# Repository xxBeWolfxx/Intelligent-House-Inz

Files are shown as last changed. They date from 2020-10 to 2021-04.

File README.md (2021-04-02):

# Projekt, praca dyplomowa pod tytułem "Układ sterowania inteligentnego budynku mieszkalnego "
Projekt został zrealizowany w ramach pracy dyplomowej na uczelni wyższej, Politechniki Poznańskiej. Miała ona na celu opracowania systemu do zarządzania domostwem.

## Założenia aplikacji: 
### Funkcje aplikacji:
   - Opracowanie układu kontroli i sterowania budynkiem mieszkalnym
   - Opracowanie mobilnego interfejsu uzytkownika
   - Opracowanie układu komunikacji głosowej

Aplikacja składa się z 4 elementów: Komputera (asystent Google'a, serwer, baza danych), Aplikacja (interfejs użytkownika), ESP Sensors (pobieranie danych z czujników), ESP Outputs (zarządzanie załączaniem urządzeń).
## Komputer.
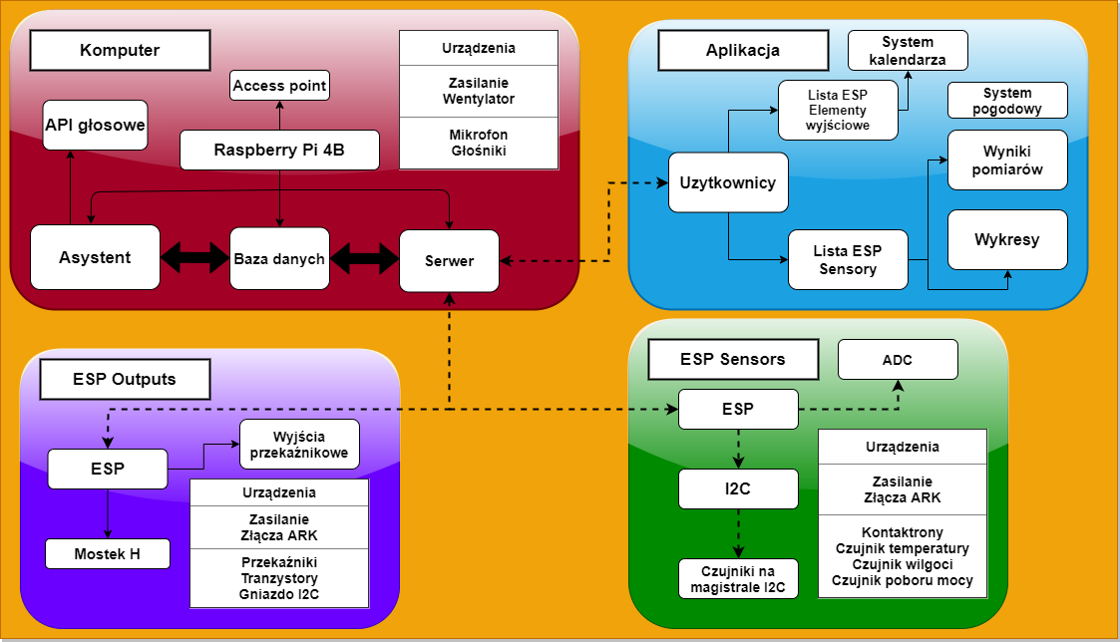
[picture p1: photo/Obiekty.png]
Diagram

Jako komputer został zaimplementowany komputer Raspberry Pi 4B, który posiada w sobie instancje:
#### Serwer.
Został zrealizowany za pomocą frameworku Django oraz Django REST framework. Została stworzona strona administracyjna do szybkiego modelowania informacji w bazie.
Link: https://github.com/xxBeWolfxx/Django-server

### Baza danych.
Ze względu na wykorzystanie systemu operacyjnego Debian została zaimplementowana baza SQL w dystrybucji MariaDB. Baza posiada tablice: Użytkownik, ESP Sensor, ESP Output. Tablice ESP Sensor oraz ESP Output są w relacji Many-to-Many z tablicą Użytkownik.

#### Asystent.
Asystent został zaimplementowany jako gotowe rozwiązanie GassistPI[www] https://gassistpi-documentation.readthedocs.io. Wymieniony SDK korzysta z rozwiązań Asystenta Google'a. Zostały również dodane skrypty do sterowania płytką ESP Outputs. 

### Płytki PCB.
Zaprojektowano dwa typy płytek w programie Eagle, które są uniwersalne i mają możliwość podłączenia różnych urządzeń. Napięcie zasilające może osiągać wartość od 10 do 20 Voltów DC. 
#### ESP Sensors
Zawiera:
- 4 porty ADC (2x port z 5V, 2x port 3V3),
- 5 portów kontaktronów, badanie statusu pinów czy zostały zwarte czy rozwarte.
- 4 porty magistrali I2C (2x port z 5V, 2x port 3V3).

#### ESP Outputs
- 5 portów przekaźnikowych zasilonych napięciem zasilania. 
- 2 porty do sterowania silnikiem DC.

### Aplikacja
Składa się ona z dwóch aktywności: uwierzytelnienie użytkownika oraz zarządzanie urządzeniami i sensorami w sieci. Zaimplementowano wykresy wartości czujników. Aplikacja współpracuje ściśle z serwerem i komunikuje się z nim po protokole HTTP REST Api.

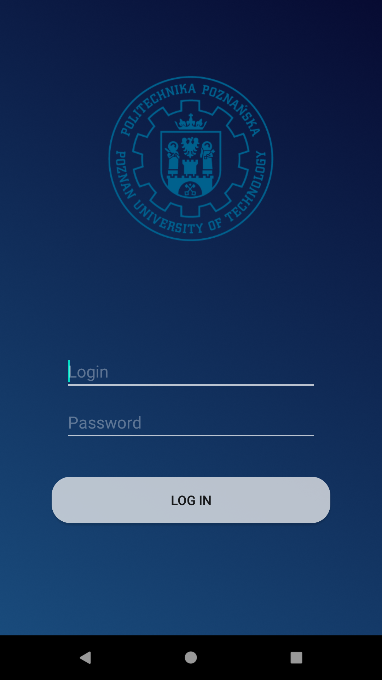
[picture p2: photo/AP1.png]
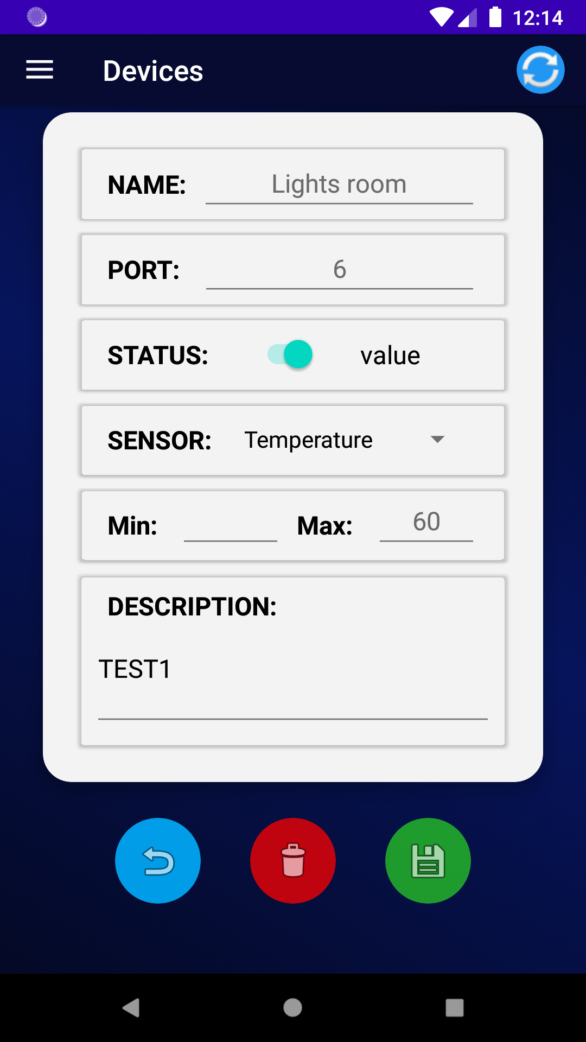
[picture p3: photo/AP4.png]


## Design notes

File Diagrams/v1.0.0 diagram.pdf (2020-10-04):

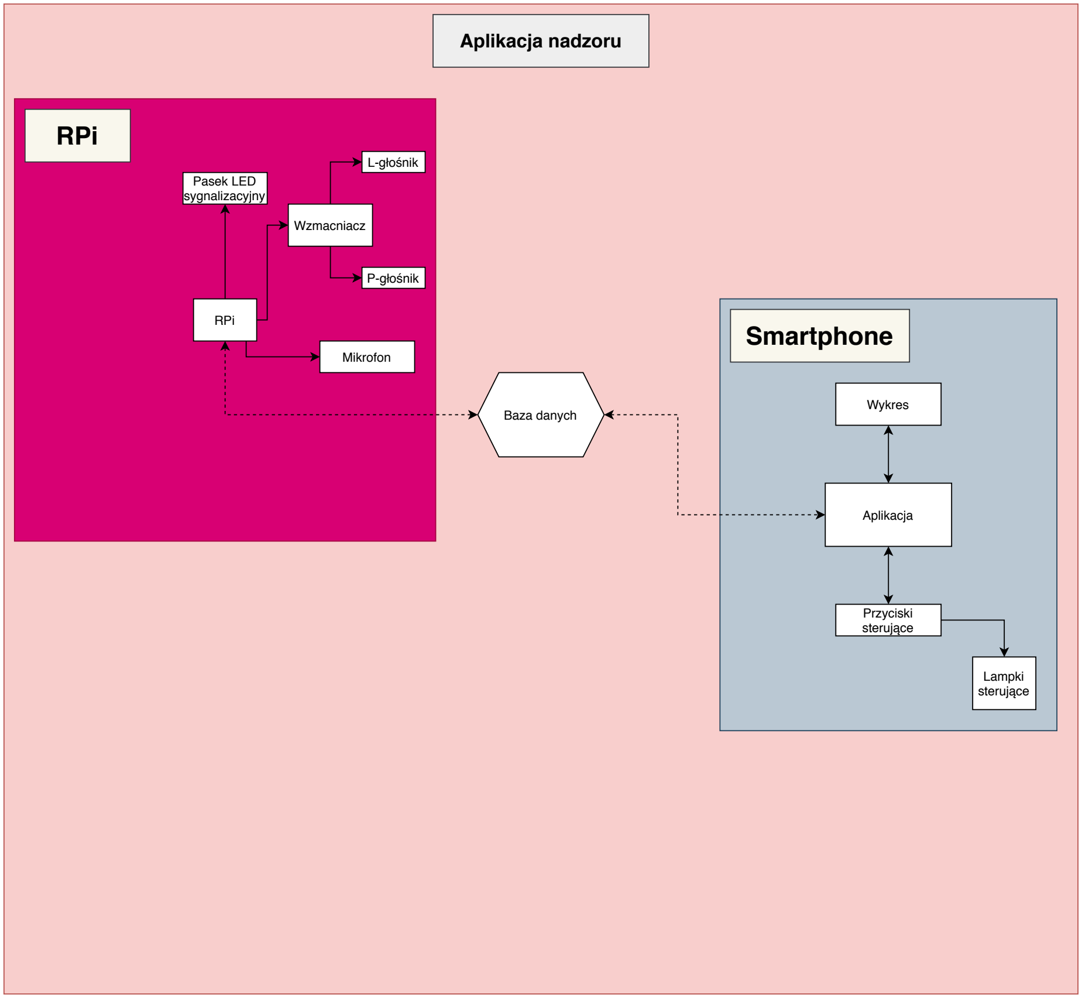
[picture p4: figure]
Aplikacja nadzoru; RPi; Smartphone; Wzmacniacz; L-głośnik; P-głośnik; Mikrofon; Baza danych; Aplikacja; Pasek LED sygnalizacyjny; Wykres; Przyciski sterujące; Lampki sterujące

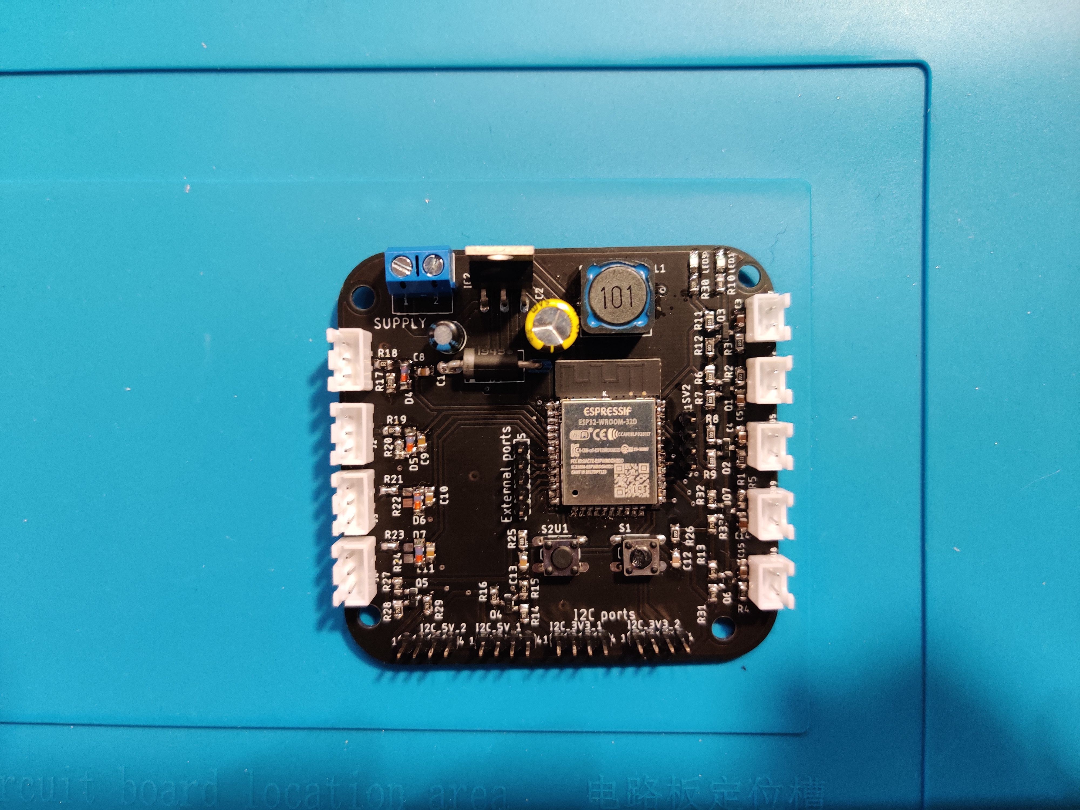
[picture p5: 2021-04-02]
photo/sensor.jpg

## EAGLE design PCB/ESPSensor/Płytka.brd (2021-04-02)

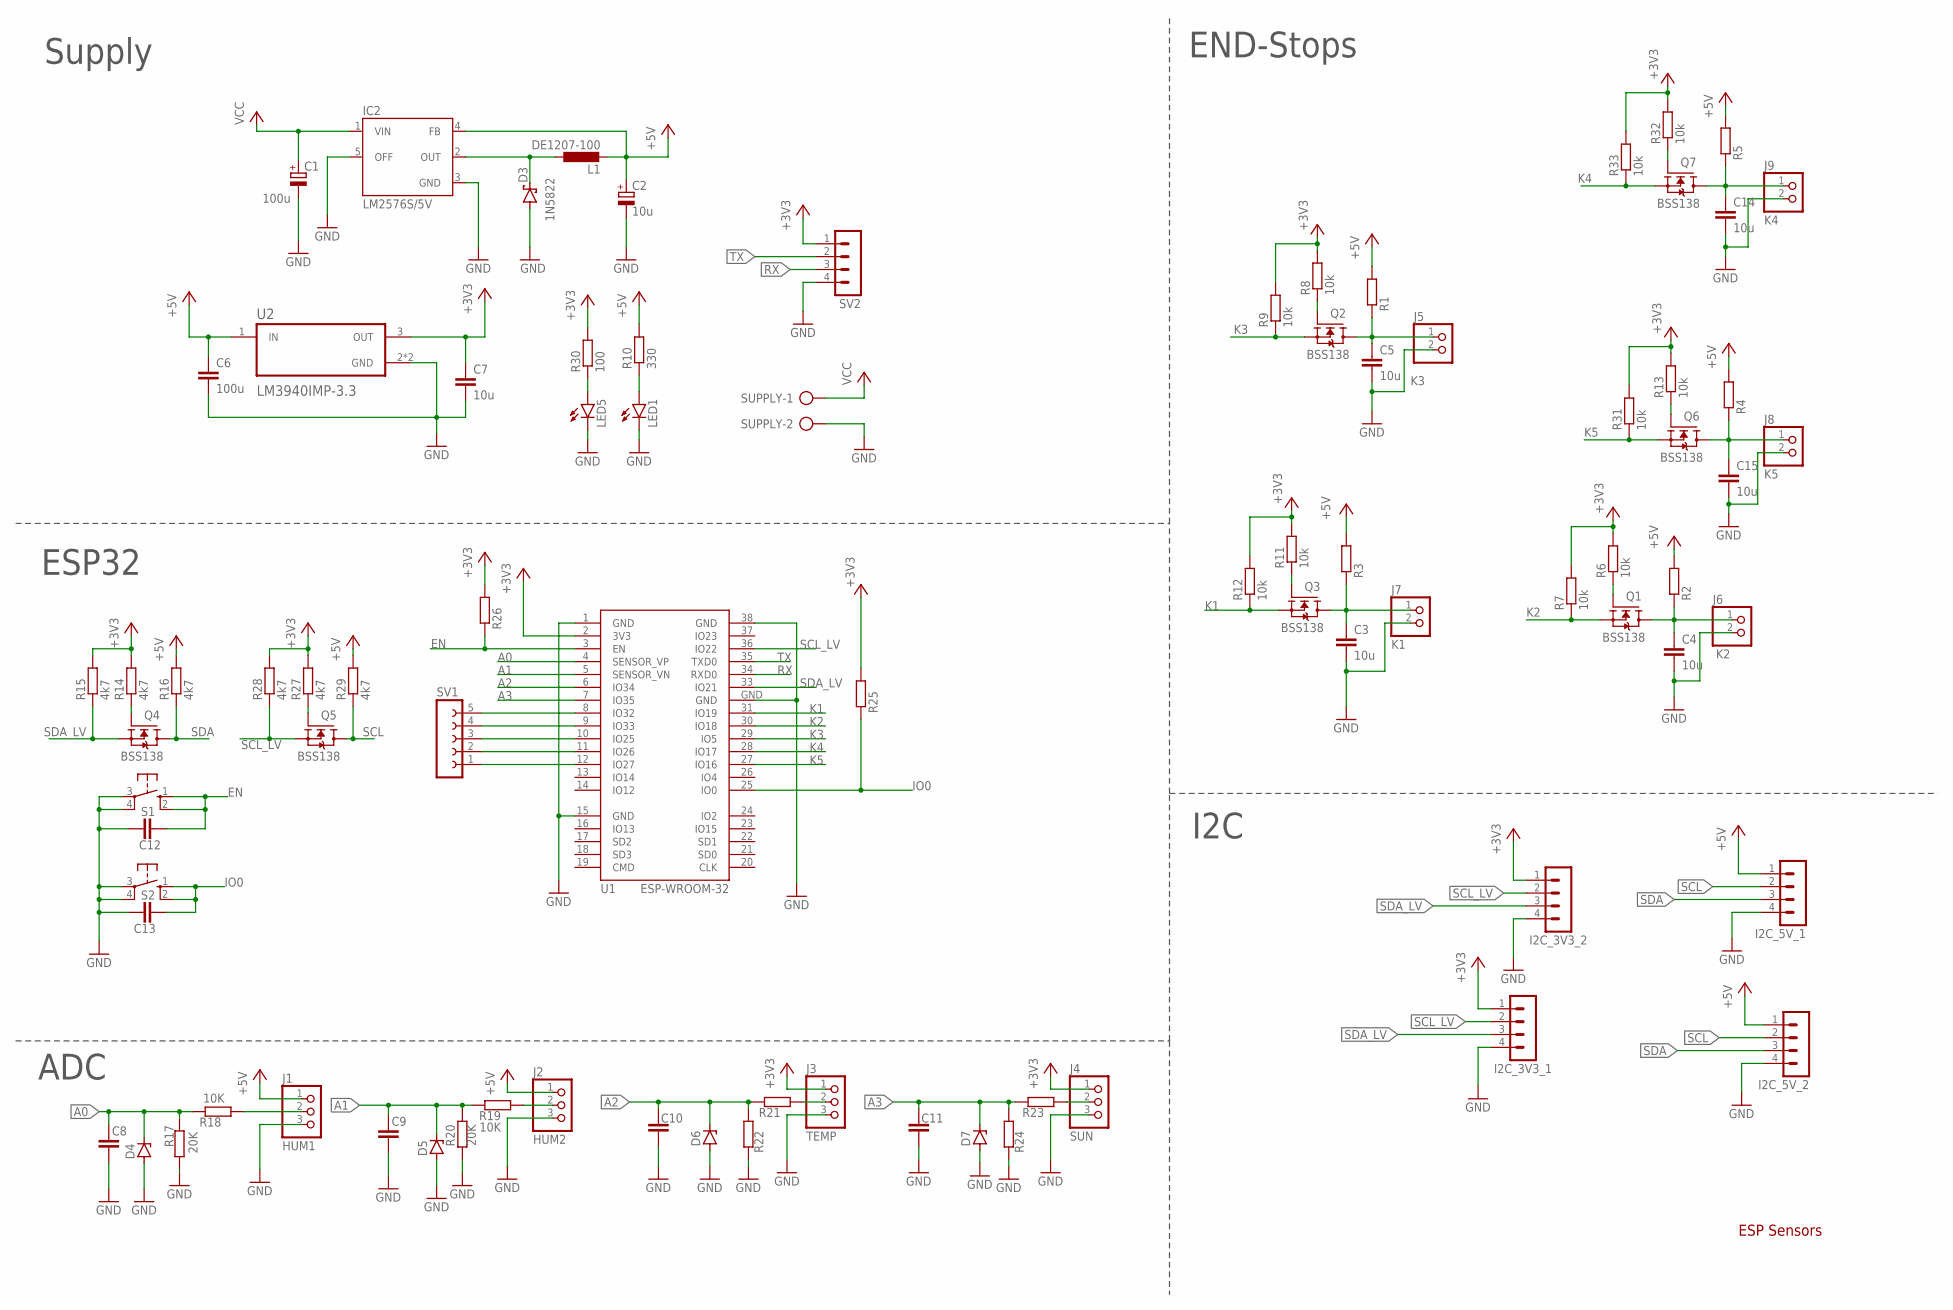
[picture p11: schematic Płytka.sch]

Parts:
C1: 100u; E2,5-6
C2: 10u; E3,5-8
C3, C4, C5, C7, C14, C15: 10u; C0805K
C6: 100u; C0805K
C8, C9, C10, C11, C12, C13: C-EUC0805K; C0805K
D3: 1N5822; C4111-15
D4, D5, D6, D7: ZENER-DIODESOD80C; SOD80C
I2C_3V3_1, I2C_3V3_2, I2C_5V_1, I2C_5V_2: MA04-1
IC2: LM2576S/5V; TO220-5
J1: HUM1; W_TYPE_2MM_3_N
J2: HUM2; W_TYPE_2MM_3_N
J3: TEMP; W_TYPE_2MM_3_N
J4: SUN; W_TYPE_2MM_3_N
J5: K3; W_TYPE_2MM_2_N
J6: K2; W_TYPE_2MM_2_N
J7: K1; W_TYPE_2MM_2_N
J8: K5; W_TYPE_2MM_2_N
J9: K4; W_TYPE_2MM_2_N
L1: DE1207-100; DE1207
LED1, LED5: LEDSML0805; SML0805
Q1, Q2, Q3, Q4, Q5, Q6, Q7: BSS138; SOT23
R1, R2, R3, R4, R5, R21, R22, R23, R24, R25, R26: R-EU_R0805; R0805
R6, R7, R8, R9, R11, R12, R13, R31, R32, R33: 10k; R0805
R10: 330; R0805
R14, R15, R16, R27, R28, R29: 4k7; R0805
R17, R20: 20K; R0805
R18, R19: 10K; R0805
R30: 100; R0805
S1, S2: 10-XX; B3F-10XX
SUPPLY: AK500/2-H
SV1: FE05-1
SV2: MA04-1
U1: ESP-WROOM-32
U2: LM3940IMP-3.3; SOT230P700X180-4N

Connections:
+3V3: C7.1, I2C_3V3_1.1, I2C_3V3_2.1, J3.1, J4.1, R6.2, R7.2, R8.2, R9.2, R11.2, R12.2, R13.2, R14.2, R15.2, R25.2, R26.2, R27.2, R28.2, R30.2, R31.2, R32.2, R33.2, SV2.1, U1.2 (3V3), U2.3 (OUT)
+5V: C2.+, C6.1, I2C_5V_1.1, I2C_5V_2.1, IC2.4 (FB), J1.1, J2.1, L1.2, R1.2, R2.2, R3.2, R4.2, R5.2, R10.2, R16.2, R29.2, U2.1 (IN)
A0: C8.1, D4.C, R17.2, R18.2, U1.4 (SENSOR_VP)
A1: C9.1, D5.C, R19.2, R20.1, U1.5 (SENSOR_VN)
A2: C10.1, D6.C, R21.2, R22.1, U1.6 (IO34)
A3: C11.1, D7.C, R23.2, R24.1, U1.7 (IO35)
EN: C12.2, R26.1, S1.1 (S), S1.2 (S1), U1.3 (EN)
GND: C1.-, C2.-, C3.2, C4.2, C5.2, C6.2, C7.2, C8.2, C9.2, C10.2, C11.2, C12.1, C13.1, C14.2, C15.2, D3.A, D4.A, D5.A, D6.A, D7.A, I2C_3V3_1.4, I2C_3V3_2.4, I2C_5V_1.4, I2C_5V_2.4, IC2.3 (GND), IC2.5 (OFF), J1.3, J2.3, J3.3, J4.3, J5.2, J6.2, J7.2, J8.2, J9.2, LED1.C, LED5.C, R17.1, R20.2, R22.2, R24.2, S1.3, S1.4 (P1), S2.3, S2.4 (P1), SUPPLY.2, SV2.4, U1.1 (GND), U1.15 (GND), U1.38 (GND), U1.GND, U2.2 (GND), U2.4 (GND)
IO0: C13.2, R25.1, S2.1 (S), S2.2 (S1), U1.25 (IO0)
K1: Q3.2 (S), R12.1, U1.31 (IO19)
K2: Q1.2 (S), R7.1, U1.30 (IO18)
K3: Q2.2 (S), R9.1, U1.29 (IO5)
K4: Q7.2 (S), R33.1, U1.28 (IO17)
K5: Q6.2 (S), R31.1, U1.27 (IO16)
unnamed: C5.1, J5.1, Q2.3 (D), R1.1
unnamed: C4.1, J6.1, Q1.3 (D), R2.1
unnamed: LED1.A, R10.1
unnamed: Q4.1 (G), R14.1
unnamed: C3.1, J7.1, Q3.3 (D), R3.1
unnamed: C14.1, J9.1, Q7.3 (D), R5.1
unnamed: C15.1, J8.1, Q6.3 (D), R4.1
unnamed: Q5.1 (G), R27.1
unnamed: J1.2, R18.1
unnamed: SV1.5, U1.8 (IO32)
unnamed: Q1.1 (G), R6.1
unnamed: SV1.4, U1.9 (IO33)
unnamed: Q2.1 (G), R8.1
unnamed: SV1.3, U1.10 (IO25)
unnamed: J4.2, R23.1
unnamed: Q3.1 (G), R11.1
unnamed: SV1.2, U1.11 (IO26)
unnamed: J2.2, R19.1
unnamed: D3.C, IC2.2 (OUT), L1.1
unnamed: Q6.1 (G), R13.1
unnamed: J3.2, R21.1
unnamed: SV1.1, U1.12 (IO27)
unnamed: LED5.A, R30.1
unnamed: Q7.1 (G), R32.1
RX: SV2.3, U1.34 (RXD0)
SCL: I2C_5V_1.2, I2C_5V_2.2, Q5.3 (D), R29.1
SCL_LV: I2C_3V3_1.2, I2C_3V3_2.2, Q5.2 (S), R28.1, U1.36 (IO22)
SDA: I2C_5V_1.3, I2C_5V_2.3, Q4.3 (D), R16.1
SDA_LV: I2C_3V3_1.3, I2C_3V3_2.3, Q4.2 (S), R15.1, U1.33 (IO21)
TX: SV2.2, U1.35 (TXD0)
VCC: C1.+, IC2.1 (VIN), SUPPLY.1

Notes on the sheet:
Supply
ESP32
ADC
I2C
END-Stops
ESP Sensors

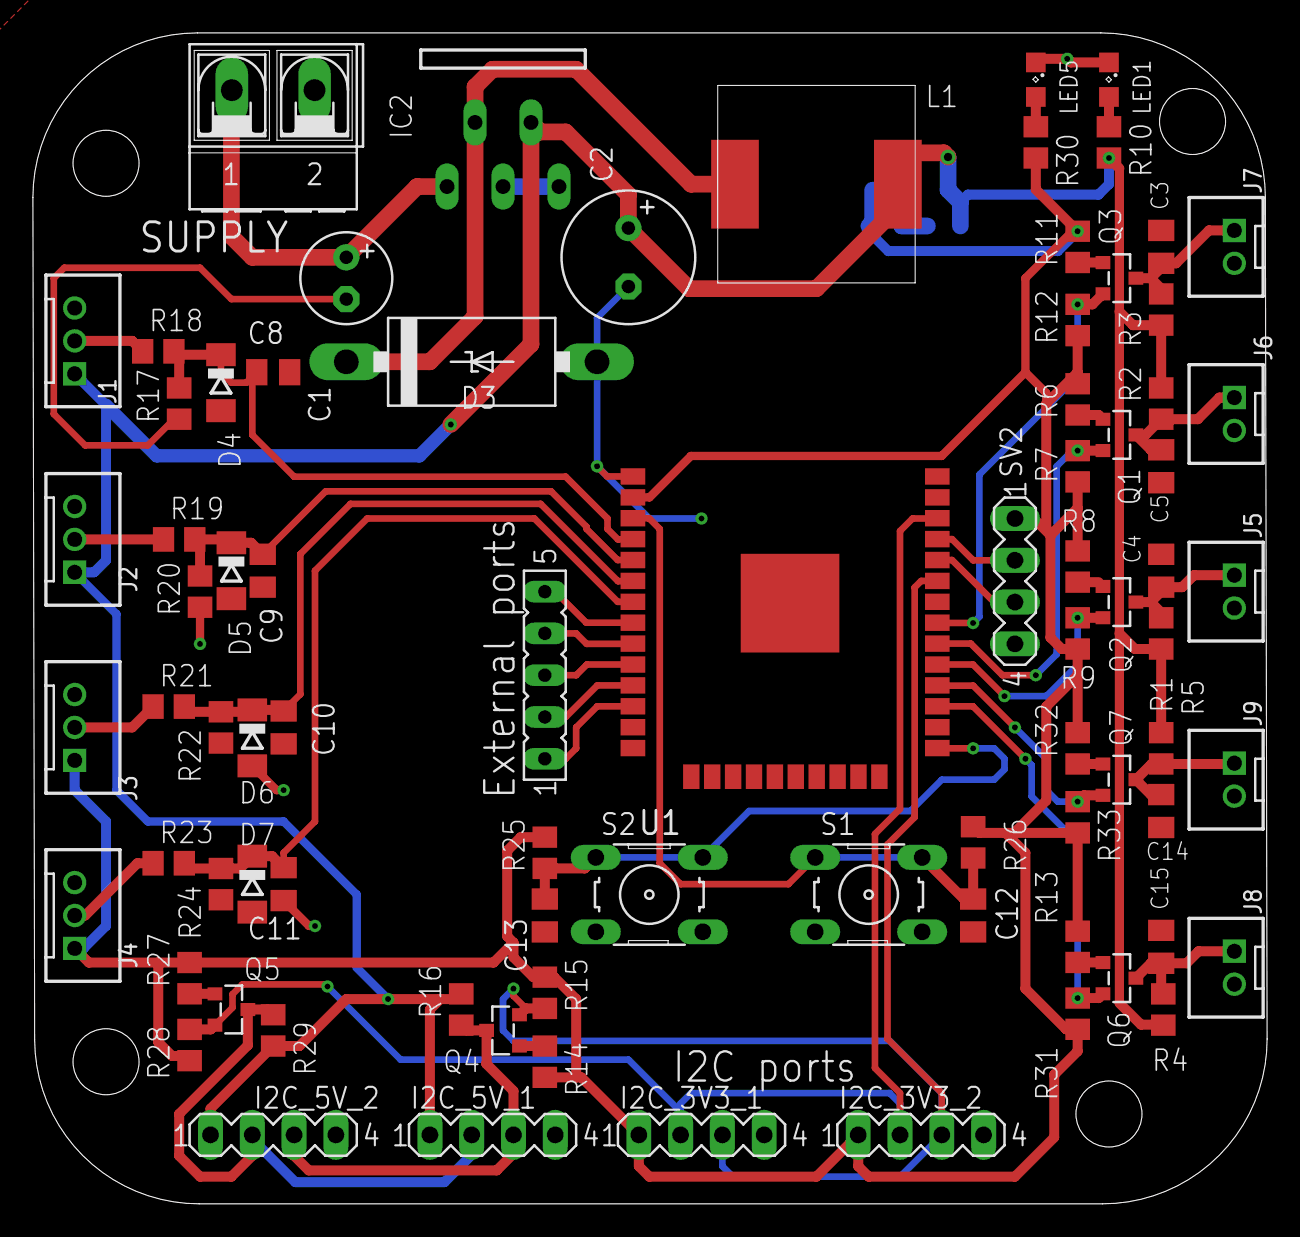
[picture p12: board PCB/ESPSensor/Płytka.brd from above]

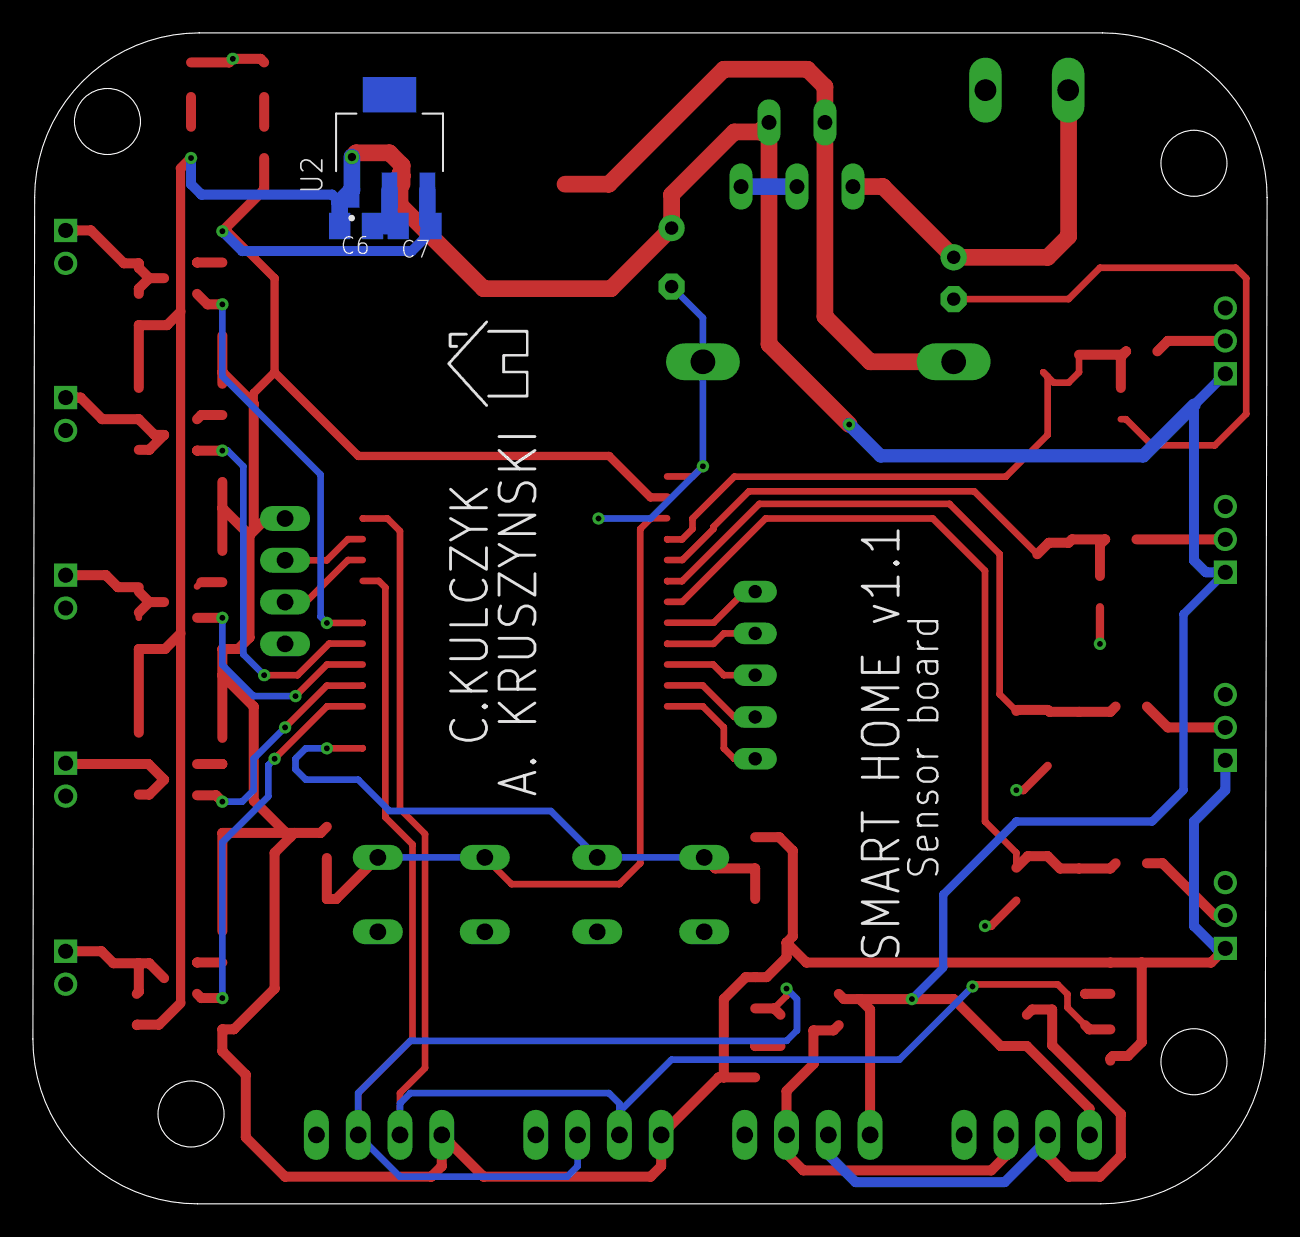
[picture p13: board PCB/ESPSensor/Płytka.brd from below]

Board: 2 copper layers, 75.0 x 71.2 mm, 84 parts (3 on the bottom side), 45 nets.

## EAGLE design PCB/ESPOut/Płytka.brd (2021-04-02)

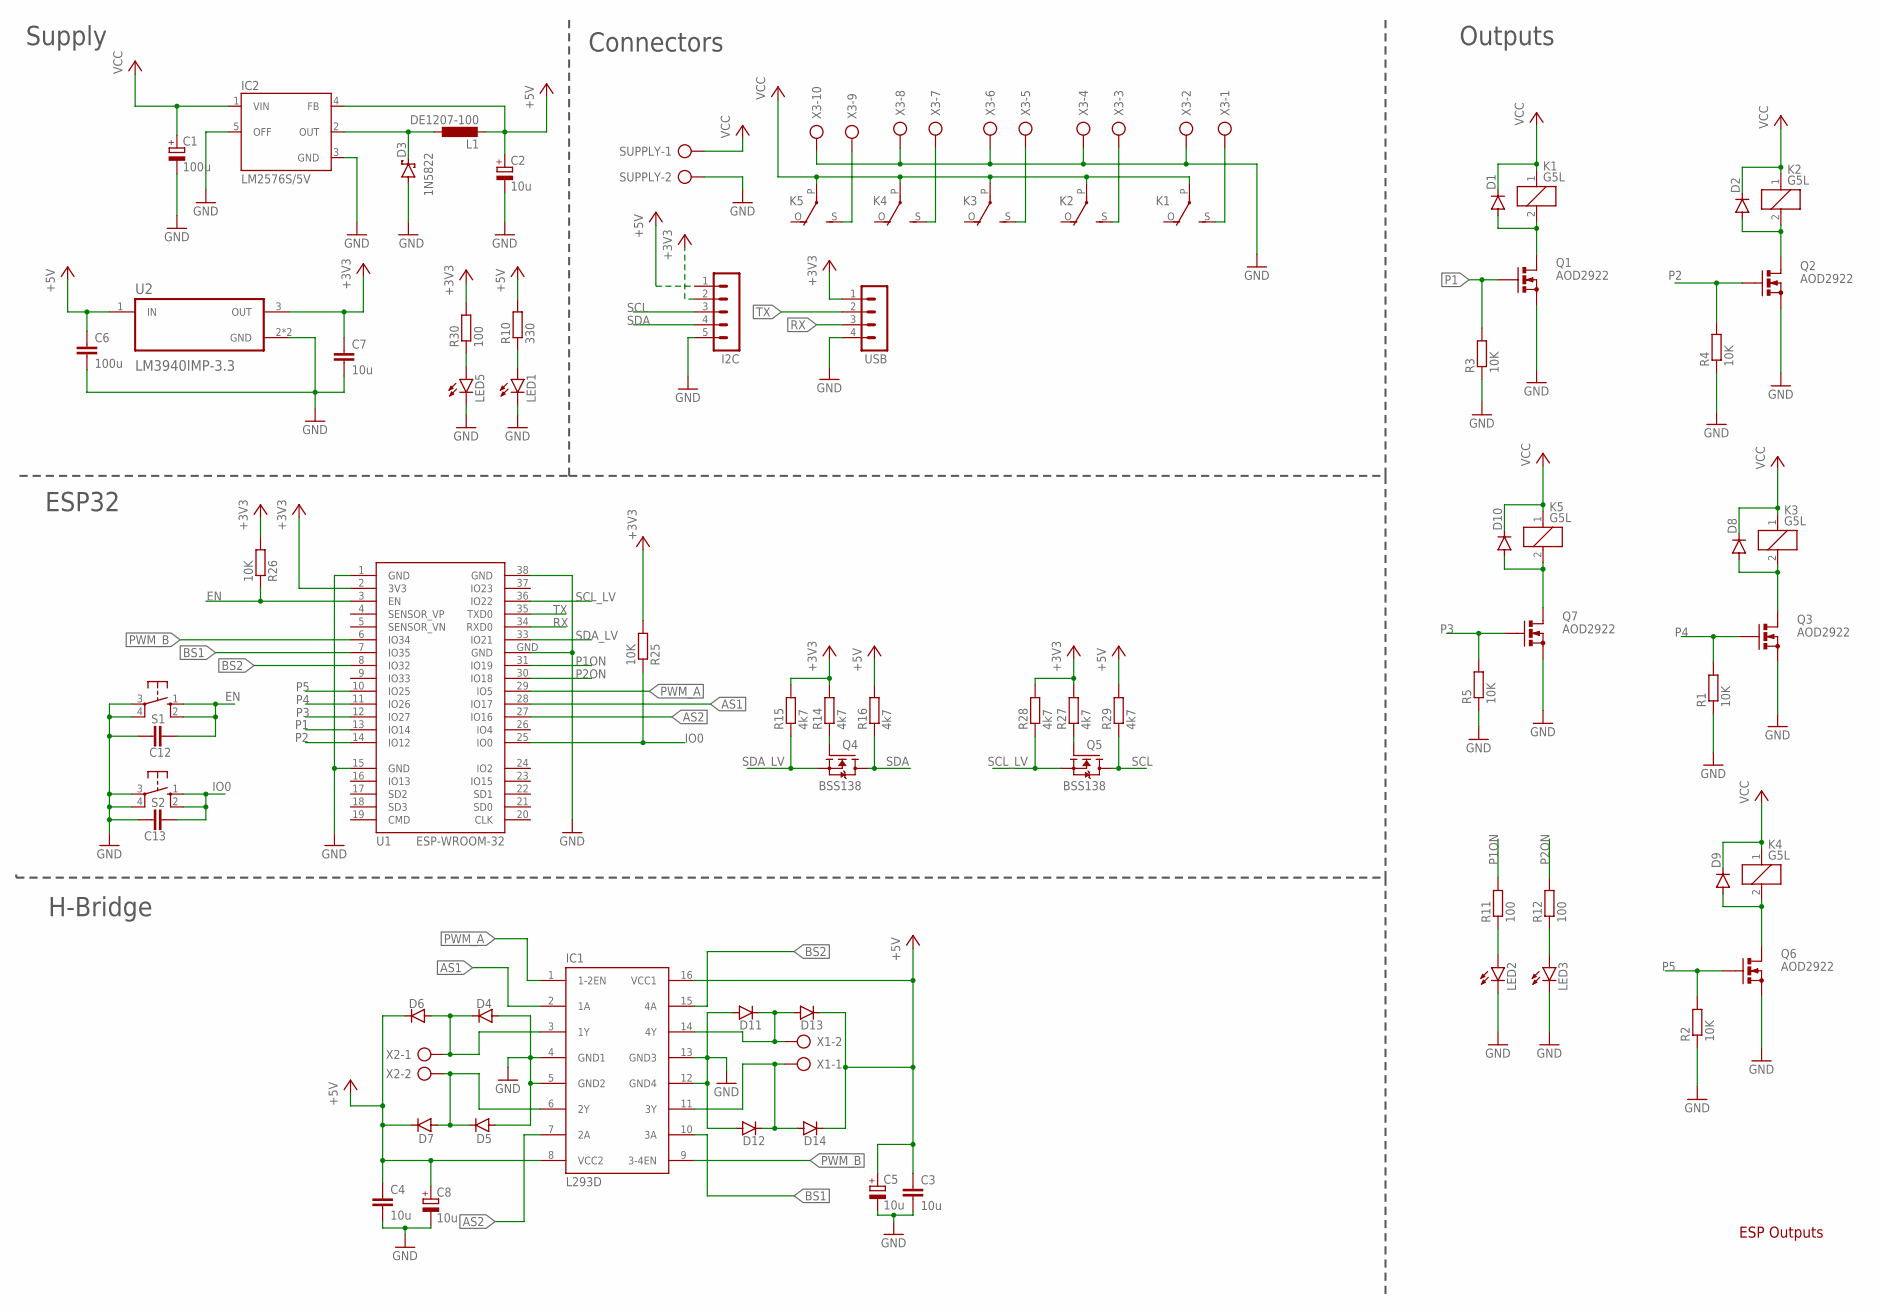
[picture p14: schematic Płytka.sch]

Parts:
C1: 100u; E2,5-6
C2: 10u; E3,5-8
C3, C4, C7: 10u; C0805K
C5, C8: 10u; E5-8,5
C6: 100u; C0805K
C12, C13: C-EUC0805K; C0805K
D1, D2, D4, D5, D6, D7, D8, D9, D10, D11, D12, D13, D14: DIODE-DO214AC; DO214AC
D3: 1N5822; C4111-15
I2C: MA05-1
IC1: L293D; DIL16
IC2: LM2576S/5V; TO220-5
K1, K2, K3, K4, K5: G5L; G5LE
L1: DE1207-100; DE1207
LED1, LED2, LED3, LED5: LEDSML0805; SML0805
Q1, Q2, Q3, Q6, Q7: AOD2922; TO252AA
Q4, Q5: BSS138; SOT23
R1, R2, R3, R4, R5, R25, R26: 10K; R0805
R10: 330; R0805
R11, R12, R30: 100; R0805
R14, R15, R16, R27, R28, R29: 4k7; R0805
S1, S2: 10-XX; B3F-10XX
SUPPLY: AK500/2-H
U1: ESP-WROOM-32
U2: LM3940IMP-3.3; SOT230P700X180-4N
USB: MA04-1
X1, X2: AK500/2
X3: AK500/10

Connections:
+3V3: C7.1, I2C.2, R14.2, R15.2, R25.2, R26.2, R27.2, R28.2, R30.2, U1.2 (3V3), U2.3 (OUT), USB.1
+5V: C2.+, C3.1, C4.1, C5.+, C6.1, C8.+, D6.C, D7.C, D13.C, D14.C, I2C.1, IC1.8 (VCC2), IC1.16 (VCC1), IC2.4 (FB), L1.2, R10.2, R16.2, R29.2, U2.1 (IN)
AS1: IC1.2 (1A), U1.28 (IO17)
AS2: IC1.7 (2A), U1.27 (IO16)
BS1: IC1.10 (3A), U1.7 (IO35)
BS2: IC1.15 (4A), U1.8 (IO32)
EN: C12.2, R26.1, S1.1 (S), S1.2 (S1), U1.3 (EN)
GND: C1.-, C2.-, C3.2, C4.2, C5.-, C6.2, C7.2, C8.-, C12.1, C13.1, D3.A, D4.A, D5.A, D11.A, D12.A, I2C.5, IC1.4 (GND1), IC1.5 (GND2), IC1.12 (GND4), IC1.13 (GND3), IC2.3 (GND), IC2.5 (OFF), LED1.C, LED2.C, LED3.C, LED5.C, Q1.2 (S), Q2.2 (S), Q3.2 (S), Q6.2 (S), Q7.2 (S), R1.1, R2.1, R3.1, R4.1, R5.1, S1.3, S1.4 (P1), S2.3, S2.4 (P1), SUPPLY.2, U1.1 (GND), U1.15 (GND), U1.38 (GND), U1.GND, U2.2 (GND), U2.4 (GND), USB.4, X3.2, X3.4, X3.6, X3.8, X3.10
IO0: C13.2, R25.1, S2.1 (S), S2.2 (S1), U1.25 (IO0)
unnamed: K5.S, X3.9
unnamed: D8.A, K3.2, Q3.3 (D)
unnamed: LED1.A, R10.1
unnamed: Q4.1 (G), R14.1
unnamed: LED2.A, R11.1
unnamed: LED3.A, R12.1
unnamed: K4.S, X3.7
unnamed: Q5.1 (G), R27.1
unnamed: K3.S, X3.5
unnamed: K2.S, X3.3
unnamed: D9.A, K4.2, Q6.3 (D)
unnamed: D1.A, K1.2, Q1.3 (D)
unnamed: D2.A, K2.2, Q2.3 (D)
unnamed: K1.S, X3.1
unnamed: D10.A, K5.2, Q7.3 (D)
unnamed: D4.C, D6.A, IC1.3 (1Y), X2.1
unnamed: D3.C, IC2.2 (OUT), L1.1
unnamed: D12.C, D14.A, IC1.11 (3Y), X1.1
unnamed: D11.C, D13.A, IC1.14 (4Y), X1.2
unnamed: LED5.A, R30.1
unnamed: D5.C, D7.A, IC1.6 (2Y), X2.2
P1: Q1.1 (G), R3.2, U1.13 (IO14)
P1ON: R11.2, U1.31 (IO19)
P2: Q2.1 (G), R4.2, U1.14 (IO12)
P2ON: R12.2, U1.30 (IO18)
P3: Q7.1 (G), R5.2, U1.12 (IO27)
P4: Q3.1 (G), R1.2, U1.11 (IO26)
P5: Q6.1 (G), R2.2, U1.10 (IO25)
PWM_A: IC1.1 (1-2EN), U1.29 (IO5)
PWM_B: IC1.9 (3-4EN), U1.6 (IO34)
RX: U1.34 (RXD0), USB.3
SCL: I2C.3, Q5.3 (D), R29.1
SCL_LV: Q5.2 (S), R28.1, U1.36 (IO22)
SDA: I2C.4, Q4.3 (D), R16.1
SDA_LV: Q4.2 (S), R15.1, U1.33 (IO21)
TX: U1.35 (TXD0), USB.2
VCC: C1.+, D1.C, D2.C, D8.C, D9.C, D10.C, IC2.1 (VIN), K1.1, K1.P, K2.1, K2.P, K3.1, K3.P, K4.1, K4.P, K5.1, K5.P, SUPPLY.1

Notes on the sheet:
Supply
Connectors
Outputs
ESP32
H-Bridge
ESP Outputs

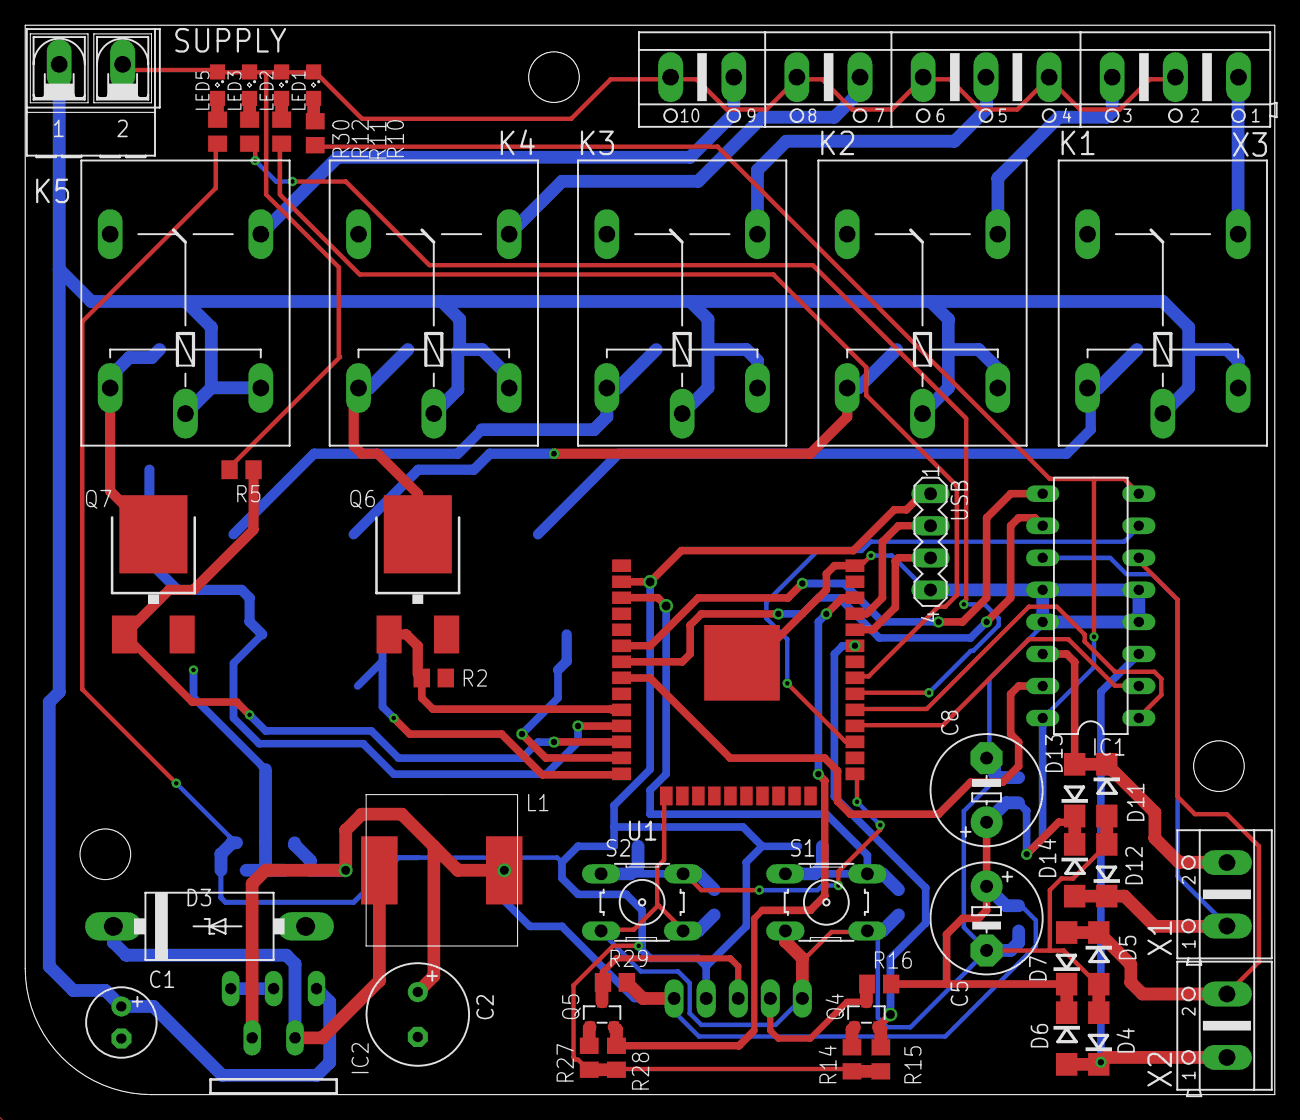
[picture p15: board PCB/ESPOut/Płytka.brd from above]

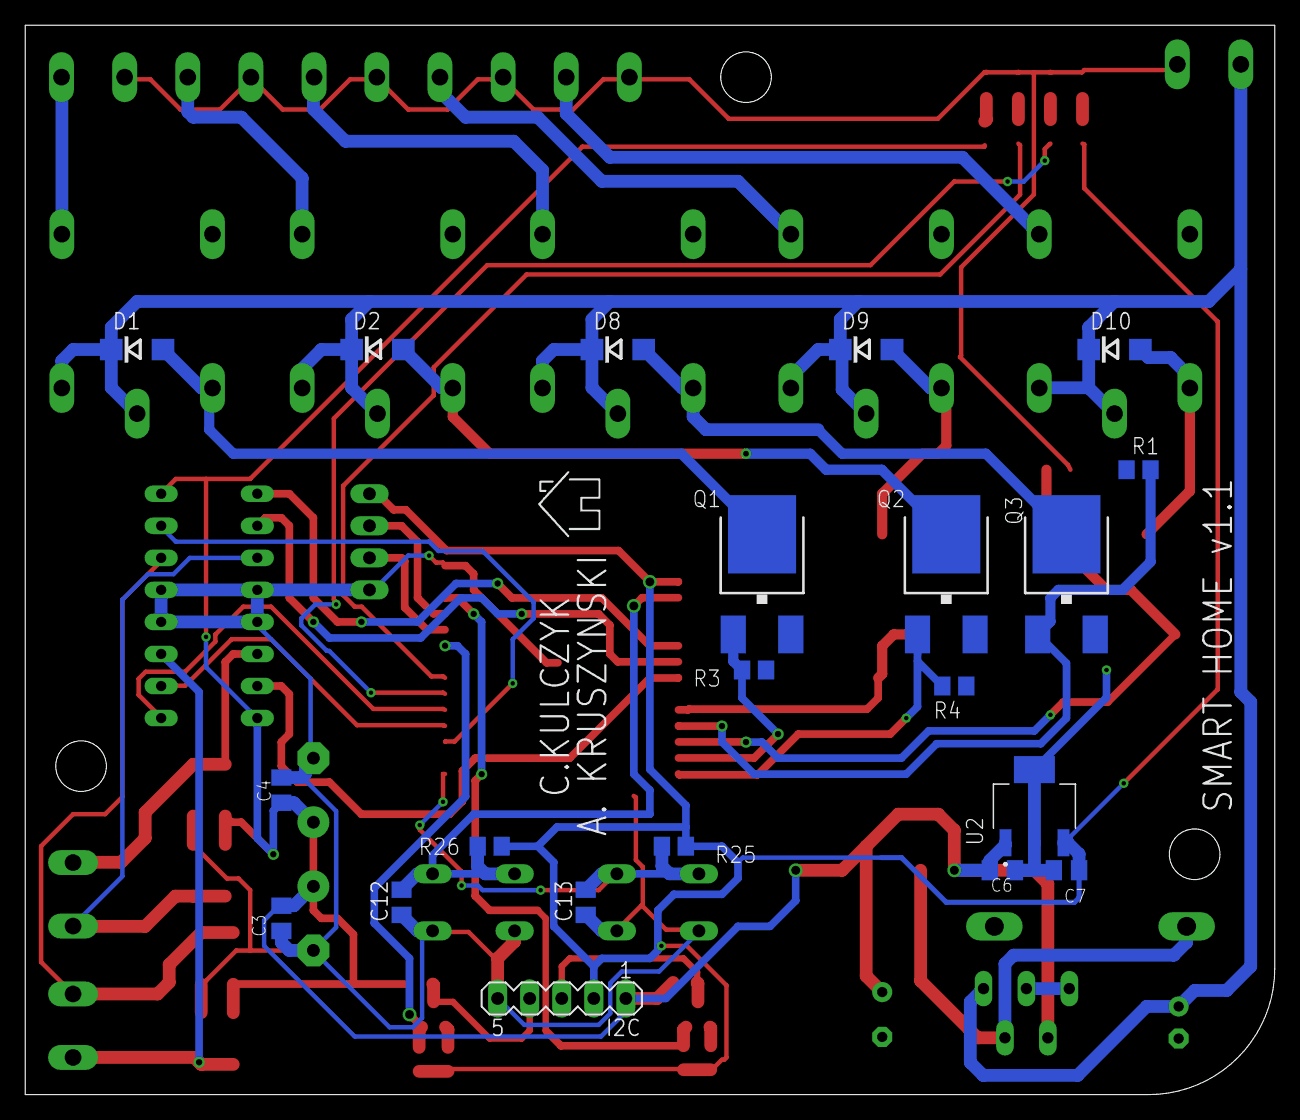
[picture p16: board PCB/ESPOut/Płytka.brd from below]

Board: 2 copper layers, 99.0 x 84.8 mm, 70 parts (21 on the bottom side), 46 nets.

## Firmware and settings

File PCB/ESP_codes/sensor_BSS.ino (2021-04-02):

#include <WiFi.h>
#include <HTTPClient.h>
#include "ArduinoJson.h"
#include <stdio.h>
#include <OneWire.h>
#include <DallasTemperature.h>

int A_IDs[] = {2, 5, 6, 8};
int K_IDs[] = {3, 4, 7};

int A_IDcount = sizeof(A_IDs) / sizeof(int);
int K_IDcount = sizeof(K_IDs) / sizeof(int);

const char *ssid = "malinka";
const char *password = "malinka312";

OneWire ds(32);
DallasTemperature sensors(&ds);

char serverName[46] = {"http://192.168.4.1:8000/sh/espsensordetail/"};

class sensory
{
protected:
  char serverPath[49];

public:
  bool active;
  int ID;
  int pin;
  float value;
  void init(int ID)
  {
    this->ID = ID;
    snprintf(serverPath, 49, "%s%i/", serverName, ID);
    HTTPClient http;
    http.begin(serverPath);
    StaticJsonDocument<200> jsonDoc;

    int httpResponseCode = http.GET();

    if (httpResponseCode > 0)
    {

      Serial.print("HTTP Response code: ");
      Serial.println(httpResponseCode);
      String payload = http.getString();

      deserializeJson(jsonDoc, payload);

      pin = jsonDoc["pin"];
      active = jsonDoc["status"];
    }
    else
    {
      Serial.print("Error code: ");
      Serial.println(httpResponseCode);
    }
    http.end();
  }
};

class A_sensory : public sensory
{
public:
  void read_value()
  {
    if (active)
    {
      int temp;

      switch (pin)
      {
      case 32:
        sensors.requestTemperatures();
        float temperatureC = sensors.getTempCByIndex(0);
        if (abs(temp - value) > 1)
        {
          value = temp;
          this->POST();
        }
        break;
      case 34: //fotorezystor
        temp = map(analogRead(pin), 410, 3685, 0, 20);
        if (abs(temp - value) > 1)
        {
          value = temp;
          this->POST();
        }
        break;
      case 35: //czujnik prądu
        temp = analogRead(pin) * (5 / 4095);
        float curent = (temp - 2.5) * 100;
        if (abs(temp - value) > 1)
        {
          value = temp;
          this->POST();
        }
        break;
      case 36: //czujnik wilgotności gleby
        temp = map(analogRead(pin), 4095, 0, 0, 100);
        if (abs(temp - value) > 1)
        {
          value = temp;
          this->POST();
        }
        break;
      case 39: //termometr
        temp = map(analogRead(pin), 186, 1241, -40, 50);
        if (abs(temp - value) > 1)
        {
          value = temp;
          this->POST();
        }
        break;
      default:
        temp = analogRead(pin);
        if (abs(temp - value) > 5)
        {
          value = temp;
          this->POST();
        }
        break;
      }
    }
  }
  void POST()
  {
    HTTPClient http;
    http.begin(serverPath);

    char payload[80];
    snprintf(payload, 80, "{\"pin\":%i,\"valueTemp\":%i,\"valueAvgDay\":\"\",\"valueAvgWeek\":\"\"}", pin, value);
    http.addHeader("Content-Type", "application/json");
    int httpResponseCode = http.POST(payload);

    Serial.print("Json: ");
    Serial.println(payload);

    if (httpResponseCode > 0)
    {
      Serial.print("HTTP Response code: ");
      Serial.println(httpResponseCode);
    }
    else
    {
      Serial.print("Error code: ");
      Serial.println(httpResponseCode);
    }
    http.end();
  }
};
class K_sensory : public sensory
{
public:
  void read_value()
  {
    if (active)
    {
      int temp;
      if (digitalRead(pin))
        temp = 0;
      else
        temp = 1;
      if (value != temp)
      {
        value = temp;
        this->POST();
      }
    }
  }

  void POST()
  {
    HTTPClient http;
    http.begin(serverPath);

    char payload[80];
    snprintf(payload, 80, "{\"pin\":%i,\"valueTemp\":%i}", pin, value);
    http.addHeader("Content-Type", "application/json");
    int httpResponseCode = http.POST(payload);

    Serial.print("Json: ");
    Serial.println(payload);

    if (httpResponseCode > 0)
    {
      Serial.print("HTTP Response code: ");
      Serial.println(httpResponseCode);
    }
    else
    {
      Serial.print("Error code: ");
      Serial.println(httpResponseCode);
    }
    http.end();
  }
};

A_sensory A_sensor[4];
K_sensory K_sensor[5];
unsigned long lastTime = 0;
unsigned long timerDelay = 2000;

void setup()
{
  Serial.begin(115200);

  WiFi.begin(ssid, password);
  Serial.println("Connecting");
  while (WiFi.status() != WL_CONNECTED)
  {
    delay(500);
    Serial.print(".");
  }
  Serial.println("");
  Serial.print("Connected to WiFi network with IP Address: ");
  Serial.println(WiFi.localIP());

  if (WiFi.status() == WL_CONNECTED)
  {
    for (int i = 0; i < A_IDcount; i++)
    {
      A_sensor[i].init(A_IDs[i]);
    }
    for (int i = 0; i < K_IDcount; i++)
    {
      K_sensor[i].init(K_IDs[i]);
      pinMode(K_sensor[i].pin, INPUT);
    }
  }
  else
  {
    Serial.println("WiFi Disconnected");
  }
}

void loop()
{
  for (int i = 0; i < K_IDcount; i++)
  {
    K_sensor[i].read_value();
  }
  if ((millis() - lastTime) > timerDelay)
  {
    if (WiFi.status() == WL_CONNECTED)
    {

      for (int i = 0; i < A_IDcount; i++)
      {
        A_sensor[i].read_value();
      }
    }
    else
    {
      Serial.println("WiFi Disconnected");
    }
    lastTime = millis();
  }
}

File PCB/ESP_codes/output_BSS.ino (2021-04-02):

#include <WiFi.h>
#include <HTTPClient.h>
#include "ArduinoJson.h"

const char* ssid = "malinka";
const char* password = "malinka312";

char serverName[43] = {"http://192.168.4.1:8000/sh/espoutdetail/"};
int IDs[]={1,2,6,7,5};
int IDcount=sizeof(IDs)/sizeof(int);

unsigned long lastTime = 0;
unsigned long timerDelay = 1000;

class aktory{
  protected:
    char serverPath[46];
  public:
    bool active;
    int ID;
    int pin;
    void init(int ID){
      this->ID=ID;
      snprintf(serverPath,46,"%s%i/",serverName,ID);
      HTTPClient http;
      http.begin(serverPath);
      StaticJsonDocument<300> jsonDoc;
      
      int httpResponseCode = http.GET();
      
      if (httpResponseCode>0) {
        Serial.print("HTTP Response code: ");
        Serial.println(httpResponseCode);
        String payload = http.getString();
        
        deserializeJson(jsonDoc,payload);

        pin=jsonDoc["pin"];
      }
      else {
        Serial.print("Error code: ");
        Serial.println(httpResponseCode);
      }
      http.end();
    }
    void update_value(){
      HTTPClient http;
      http.begin(serverPath);
      StaticJsonDocument<300> jsonDoc;
      
      int httpResponseCode = http.GET();
      
      if (httpResponseCode>0) {
        Serial.print("HTTP Response code: ");
        Serial.println(httpResponseCode);
        String payload = http.getString();
        Serial.print("Payload: ");
        Serial.println(payload);
        
        deserializeJson(jsonDoc,payload);

        active=jsonDoc["status"];
          digitalWrite(pin,active);
        
      }
      else {
        Serial.print("Error code: ");
        Serial.println(httpResponseCode);
      }
      http.end();
    }
};
    

aktory aktor[6];

void setup() {
  Serial.begin(115200); 
  pinMode(12,OUTPUT);
  pinMode(14,OUTPUT);
  pinMode(25,OUTPUT);
  pinMode(26,OUTPUT);
  pinMode(27,OUTPUT);
  pinMode(5,OUTPUT);
  pinMode(17,OUTPUT);
  digitalWrite(17,HIGH);
  pinMode(16,OUTPUT);
  digitalWrite(16,LOW);
  
  WiFi.begin(ssid, password);
  Serial.println("Connecting");
  while(WiFi.status() != WL_CONNECTED) {
    delay(500);
    Serial.print(".");
  }
  Serial.println("");
  Serial.print("Connected to WiFi network with IP Address: ");
  Serial.println(WiFi.localIP());

  for(int i=0;i<IDcount;i++){
    aktor[i].init(IDs[i]);
  }
  
}

void loop() {
  
  if ((millis() - lastTime) > timerDelay) {
    if(WiFi.status()== WL_CONNECTED){
      HTTPClient http;

      for(int i=0;i<IDcount;i++){
        aktor[i].update_value();
      }
    }
    else {
      Serial.println("WiFi Disconnected");
    }
    lastTime = millis();
  }
}

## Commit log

2020-10-19 Add RPi's schematic
    [RPi.brd, RPi.sch]
2020-11-01 Add fragments and they are activated in nav_menu
    [app_bar_main.xml]
2020-11-15 Add PCBs
    [Płytka.brd, Płytka.sch]
2020-12-03 Add new PCBs
    [Płytka.brd, Płytka.sch]
2020-12-10 menu, buttons
    [app_bar_main.xml]
2021-01-05 add inputs, outputs layouts; refresh button; charts modifications
    [app_bar_main.xml]
2021-01-21 Add new buttons
    [app_bar_main.xml]
2021-02-02 Creating charts
    [Płytka.brd, Płytka.sch]

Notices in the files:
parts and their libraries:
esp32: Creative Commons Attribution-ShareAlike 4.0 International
